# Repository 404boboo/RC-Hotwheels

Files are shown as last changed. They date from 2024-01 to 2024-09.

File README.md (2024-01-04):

# RC-Hotwheels
This project is a remote controlled Hotwheels. Here you can find the Ki-cad design files and STM32 project

This repository contains all the files and documentation for our DIY remote-controlled Hot Wheels car. We designed our own custom PCB using KiCad, featuring a NRF24L01 transceiver(We only used it as a receiver for now) for wireless communication, an H-bridge BD6211F-E2 to control a DC motor for propulsion, a 600mAh LiPo battery for power, and a linear servo motor for precise steering control.
## Folder Structure

- `Kicad Files`: Contains the schematic and gerber files for the PCB design.
  - `Libs`: Libraries for the components used in the KiCad.
- `Stm32F070F6P6TR`: STM32Cube project folder.
## Bill of Materials (BOM)

Check out our [Bill of Materials Spreadsheet](https://1drv.ms/x/s!AkUVCTQvexeIhbBXzQdKwvWQZ13EOg?e=rf4EnU) for a detailed list of components used in this project.
## Installation and Setup

### PCB (KiCad Files)

1. Download the KiCad software from [kicad.org](https://www.kicad.org/).
2. Open the KiCad project files in the `Kicad Files` folder.
3. Generate the gerber files for manufacturing.

### STM32Cube Project

-- TODO

### Hardware

1. Assemble the custom PCB according to the provided schematic.
2. Connect the NRF24L01 transceiver
-- To be updated..

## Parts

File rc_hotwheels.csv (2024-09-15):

Source: | D:\Studia\5th_semester\bondyra_project\project\RC-Hotwheels\KiCad-Files\rc_hotwheels.kicad_sch
Date: | 1/14/2024 6:13:28 PM
Tool: | Eeschema 7.0.5
Generator: | D:\Studia\kicad\7.0\bin\scripting\plugins/bom_csv_grouped_by_value_with_fp.py
Component Count: | 14
Ref | Qnty | Value | Cmp name | Footprint | Description | Vendor | DNP
BT1 | 1 | Battery_Cell | Battery_Cell | Library:Battery_Pads | Single-cell battery
C1, C2, C4 | 3 | 1uF | 885012209003 | C1uF:CAPC2012X135N | Multilayer Ceramic Chip Capacitor WCAP-CSGP Series 1210 1000000pF X7R1210105K010DFCT10000
C3 | 1 | 4.7uF | 885012209004 | C1uF:CAPC2012X135N | Multilayer Ceramic Chip Capacitor WCAP-CSGP Series 1210 4700000pF X7R1210475K010DFCT10000
C5 | 1 | 100nF | 885012209041 | C1uF:CAPC2012X135N | Multilayer Ceramic Chip Capacitor WCAP-CSGP Series 1210 100000pF X7R1210104K050DFCT10000
C6 | 1 | 10nF | 885012209035 | C1uF:CAPC2012X135N | Multilayer Ceramic Chip Capacitor WCAP-CSGP Series 1210 10000pF X7R1210103K050DFCT10000
IC1 | 1 | BD6211F-E2 | BD6211F-E2 | BD6211F-E2:SOIC127P620X171-8N | ROHM BD6211F-E2, Full Bridge Motor Driver Half-Bridge,, 8-Pin SOP
IC2 | 1 | MIC5504-3.3YM5-TR | MIC5504-3.3YM5-TR | MIC5504-3.3YM5-TR:SOT95P280X145-5N | MICROCHIP - MIC5504-3.3YM5-TR - LDO VOLT REG, 0.3A, 3.3V, SOT-23-5
S1 | 1 | OS102011MS2QN1 | OS102011MS2QN1 | OS102011MA1QN1 | Switch Slide Miniature SPDT 0.1A 12VDC Through Hole Slide Switch SPDT On-On 0.1 A@ 12 V dc Slide
S3 | 1 | Li-Ion 18650 battery charging | OS102011MS2QN1_1 | Library:Battery_Pads | Switch Slide Miniature SPDT 0.1A 12VDC Through Hole Slide Switch SPDT On-On 0.1 A@ 12 V dc Slide
SM1 | 1 | Motor_Servo | Motor_Servo | Library:Servo_Motor | Servo Motor (Futaba, HiTec, JR connector)
U1 | 1 | STM32F070F6P6 | STM32F070F6P6 | STM32F070F6P6:SOP65P640X120-20N
U3 | 1 | NRF24L01_Breakout | NRF24L01_Breakout_1 | RF_Module:nRF24L01_Breakout | Ultra low power 2.4GHz RF Transceiver, Carrier PCB

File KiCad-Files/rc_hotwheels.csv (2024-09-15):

Source: | D:\Studia\5th_semester\bondyra_project\project\RC-Hotwheels\KiCad-Files\rc_hotwheels.kicad_sch
Date: | 1/14/2024 18:13
Tool: | Eeschema 7.0.5
Generator: | D:\Studia\kicad\7.0\bin\scripting\plugins/bom_csv_grouped_by_value_with_fp.py
Component Count: | 14
Ref | Qnty | Value | Cmp name | Footprint | Description | Vendor | Price 1 piece | Price 1 PCB | Price for 1 (10 pieces) | Price 10 PCB | Price for 1 (100 piece) | Price 100 PCB
BT1 | 1 | 600mAh | Battery_Cell | Library:Battery_Pads | Single-cell battery | unknown/allegro | PLN 32.99 | PLN 32.99 | PLN 32.99 | PLN 329.90 | PLN 32.99 | PLN 3,299.00
C1, C2, C4 | 3 | 1uF | 8.85012E+11 | C1uF:CAPC2012X135N | Multilayer Ceramic Chip Capacitor WCAP-CSGP Series 1210 1000000pF X7R1210105K010DFCT10000 | https://pl.farnell.com/en-PL | PLN 1.02 | PLN 1.02 | PLN 1.02 | PLN 10.20 | PLN 0.29 | PLN 87.00
C3 | 1 | 4.7uF | 8.85012E+11 | C1uF:CAPC2012X135N | Multilayer Ceramic Chip Capacitor WCAP-CSGP Series 1210 4700000pF X7R1210475K010DFCT10000 | https://pl.farnell.com/en-PL | PLN 0.48 | PLN 0.48 | PLN 0.48 | PLN 4.80 | PLN 0.27 | PLN 27.00
C5 | 1 | 100nF | 8.85012E+11 | C1uF:CAPC2012X135N | Multilayer Ceramic Chip Capacitor WCAP-CSGP Series 1210 100000pF X7R1210104K050DFCT10000 | https://pl.farnell.com/en-PL | PLN 0.21 | PLN 0.21 | PLN 0.21 | PLN 2.10 | PLN 0.18 | PLN 18.00
C6 | 1 | 10nF | 8.85012E+11 | C1uF:CAPC2012X135N | Multilayer Ceramic Chip Capacitor WCAP-CSGP Series 1210 10000pF X7R1210103K050DFCT10000 | https://pl.farnell.com/en-PL | PLN 0.15 | PLN 0.15 | PLN 0.15 | PLN 1.50 | PLN 0.13 | PLN 13.00
IC1 | 1 | BD6211F-E2 | BD6211F-E2 | BD6211F-E2:SOIC127P620X171-8N | ROHM BD6211F-E2, Full Bridge Motor Driver Half-Bridge,, 8-Pin SOP | https://pl.farnell.com/en-PL | PLN 10.55 | PLN 10.55 | PLN 7.69 | PLN 76.90 | PLN 7.20 | PLN 720.00
IC2 | 1 | MIC5504-3.3YM5-TR | MIC5504-3.3YM5-TR | MIC5504-3.3YM5-TR:SOT95P280X145-5N | MICROCHIP - MIC5504-3.3YM5-TR - LDO VOLT REG, 0.3A, 3.3V, SOT-23-5 | https://pl.farnell.com/en-PL | PLN 0.64 | PLN 0.64 | PLN 0.64 | PLN 6.40 | PLN 0.56 | PLN 56.00
S1 | 1 | OS102011MS2QN1 | OS102011MS2QN1 | OS102011MA1QN1 | Switch Slide Miniature SPDT 0.1A 12VDC Through Hole Slide Switch SPDT On-On 0.1 A@ 12 V dc Slide | https://pl.farnell.com/en-PL | PLN 2.79 | PLN 2.79 | PLN 2.79 | PLN 27.90 | PLN 2.02 | PLN 202.00
S3 | 1 | Li-Ion battery charging | TP4056 | Library:Battery_Pads | Switch Slide Miniature SPDT 0.1A 12VDC Through Hole Slide Switch SPDT On-On 0.1 A@ 12 V dc Slide | unknown/allegro | PLN 2.99 | PLN 2.99 | PLN 2.99 | PLN 29.90 | PLN 2.99 | PLN 299.00
SM1 | 1 | Motor_Servo | Motor_Servo | Library:Servo_Motor | Servo Motor (Futaba, HiTec, JR connector) | unknown/allegro | PLN 9.88 | PLN 9.88 | PLN 9.88 | PLN 98.80 | PLN 9.88 | PLN 988.00
U1 | 1 | STM32F070F6P6 | STM32F070F6P6 | STM32F070F6P6:SOP65P640X120-20N | Microprocessor | https://pl.farnell.com/en-PL | PLN 8.18 | PLN 8.18 | PLN 6.57 | PLN 65.70 | PLN 5.81 | PLN 581.00
U3 | 1 | NRF24L01_Breakout | NRF24L01_Breakout_1 | RF_Module:nRF24L01_Breakout | Ultra low power 2.4GHz RF Transceiver, Carrier PCB | https://sklep.msalamon.pl/ | PLN 5.99 | PLN 5.99 | PLN 5.99 | PLN 59.90 | PLN 5.99 | PLN 599.00
 | 1 |  | Silnik szczotkowy DC 1,5V-3,5V klasy 130 |  | DC motor 1,5V-3,5V | unknown/allegro | PLN 6.80 | PLN 6.80 | PLN 6.80 | PLN 68.00 | PLN 6.80 | PLN 680.00
 |  |  |  |  |  |  | Total 1 | Total 1 PCB | Total 10 | Total 10 PCB | Total 100 | Total 100 PCB
 |  |  |  |  |  |  | PLN 82.67 | PLN 82.67 | PLN 78.20 | PLN 782.00 | PLN 75.11 | PLN 7,569.00

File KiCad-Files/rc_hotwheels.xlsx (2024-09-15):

Source: | D:\Studia\5th_semester\bondyra_project\project\RC-Hotwheels\KiCad-Files\rc_hotwheels.kicad_sch
Date: | 2024-01-14 18:13
Tool: | Eeschema 7.0.5
Generator: | D:\Studia\kicad\7.0\bin\scripting\plugins/bom_csv_grouped_by_value_with_fp.py
Component Count: | 14
Ref | Qnty | Value | Cmp name | Footprint | Description | Vendor | Price 1 piece | Price 1 PCB | Price for 1 (10 pieces) | Price 10 PCB | Price for 1 (100 piece) | Price 100 PCB
BT1 | 1 | 600mAh | Battery_Cell | Library:Battery_Pads | Single-cell battery | unknown/allegro (https://allegro.pl/oferta/akumulator-bateria-gps-navi-600mah-3-7v-3-przewody-11314725293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) | PLN 32.99 | PLN 32.99 | PLN 32.99 | PLN 329.90 | PLN 32.99 | PLN 3,299.00
C1, C2, C4 | 3 | 1uF | 885012000000 | C1uF:CAPC2012X135N | Multilayer Ceramic Chip Capacitor WCAP-CSGP Series 1210 1000000pF X7R1210105K010DFCT10000 | farnell (https://pl.farnell.com/wurth-elektronik/885012207022/cap-1-f-10v-10-x7r-0805/dp/2534053) | PLN 1.02 | PLN 1.02 | PLN 1.02 | PLN 10.20 | PLN 0.29 | PLN 87.00
C3 | 1 | 4.7uF | 885012000000 | C1uF:CAPC2012X135N | Multilayer Ceramic Chip Capacitor WCAP-CSGP Series 1210 4700000pF X7R1210475K010DFCT10000 | farnell (https://pl.farnell.com/tdk/c2012x7r1a475k125ac/cap-4-7-f-10v-10-x7r-0805/dp/2346936) | PLN 0.48 | PLN 0.48 | PLN 0.48 | PLN 4.80 | PLN 0.27 | PLN 27.00
C5 | 1 | 100nF | 885012000000 | C1uF:CAPC2012X135N | Multilayer Ceramic Chip Capacitor WCAP-CSGP Series 1210 100000pF X7R1210104K050DFCT10000 | farnell (https://pl.farnell.com/wurth-elektronik/885012207016/cap-0-1-f-10v-10-x7r-0805/dp/2534051) | PLN 0.21 | PLN 0.21 | PLN 0.21 | PLN 2.10 | PLN 0.18 | PLN 18.00
C6 | 1 | 10nF | 885012000000 | C1uF:CAPC2012X135N | Multilayer Ceramic Chip Capacitor WCAP-CSGP Series 1210 10000pF X7R1210103K050DFCT10000 | farnell (https://pl.farnell.com/wurth-elektronik/885012207011/cap-0-01-f-10v-10-x7r-0805/dp/2534050) | PLN 0.15 | PLN 0.15 | PLN 0.15 | PLN 1.50 | PLN 0.13 | PLN 13.00
IC1 | 1 | BD6211F-E2 | BD6211F-E2 | BD6211F-E2:SOIC127P620X171-8N | ROHM BD6211F-E2, Full Bridge Motor Driver Half-Bridge,, 8-Pin SOP | farnell (https://pl.farnell.com/en-PL/rohm/bd6211f-e2/ic-h-bridge-driver-7v-1a-sop8/dp/1716259) | PLN 10.55 | PLN 10.55 | PLN 7.69 | PLN 76.90 | PLN 7.20 | PLN 720.00
IC2 | 1 | MIC5504-3.3YM5-TR | MIC5504-3.3YM5-TR | MIC5504-3.3YM5-TR:SOT95P280X145-5N | MICROCHIP - MIC5504-3.3YM5-TR - LDO VOLT REG, 0.3A, 3.3V, SOT-23-5 | farnell (https://pl.farnell.com/en-PL/microchip/mic5504-3-3ym5-tr/ldo-volt-reg-0-3a-3-3v-sot-23/dp/2510377?st=mic5504) | PLN 0.64 | PLN 0.64 | PLN 0.64 | PLN 6.40 | PLN 0.56 | PLN 56.00
S1 | 1 | OS102011MS2QN1 | OS102011MS2QN1 | OS102011MA1QN1 | Switch Slide Miniature SPDT 0.1A 12VDC Through Hole Slide Switch SPDT On-On 0.1 A@ 12 V dc Slide | farnell (https://pl.farnell.com/c-k-components/os102011ma1qn1/switch-spdt-0-1a-12v-pcb-r-a/dp/1201431?st=os102011ma1qn1) | PLN 2.79 | PLN 2.79 | PLN 2.79 | PLN 27.90 | PLN 2.02 | PLN 202.00
S3 | 1 | Li-Ion battery charging | TP4056 | Library:Battery_Pads | Switch Slide Miniature SPDT 0.1A 12VDC Through Hole Slide Switch SPDT On-On 0.1 A@ 12 V dc Slide | unknown/allegro (https://allegro.pl/oferta/ladowarka-akumulatora-li-ion-tp4056-5v-micro-usb-10795965827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) | PLN 2.99 | PLN 2.99 | PLN 2.99 | PLN 29.90 | PLN 2.99 | PLN 299.00
SM1 | 1 | Motor_Servo | Motor_Servo | Library:Servo_Motor | Servo Motor (Futaba, HiTec, JR connector) | unknown/allegro (https://allegro.pl/oferta/linear-serwo-1-5g-serwo-15001884361) | PLN 9.88 | PLN 9.88 | PLN 9.88 | PLN 98.80 | PLN 9.88 | PLN 988.00
U1 | 1 | STM32F070F6P6 | STM32F070F6P6 | STM32F070F6P6:SOP65P640X120-20N | Microprocessor | farnell (https://pl.farnell.com/en-PL/stmicroelectronics/stm32f070f6p6tr/mcu-32bit-48mhz-tssop-20/dp/3129808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) | PLN 8.18 | PLN 8.18 | PLN 6.57 | PLN 65.70 | PLN 5.81 | PLN 581.00
U3 | 1 | NRF24L01_Breakout | NRF24L01_Breakout_1 | RF_Module:nRF24L01_Breakout | Ultra low power 2.4GHz RF Transceiver, Carrier PCB | msalamon (https://sklep.msalamon.pl/produkt/modul-radiowy-nrf24l01-24-ghz-mini-smd/) | PLN 5.99 | PLN 5.99 | PLN 5.99 | PLN 59.90 | PLN 5.99 | PLN 599.00
 | 1 |  | Silnik szczotkowy DC 1,5V-3,5V klasy 130 |  | DC motor 1,5V-3,5V | unknown/allegro (https://allegro.pl/oferta/silnik-szczotkowy-dc-1-5v-3-5v-klasy-130-8897411135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) | PLN 6.80 | PLN 6.80 | PLN 6.80 | PLN 68.00 | PLN 6.80 | PLN 680.00
 |  |  |  |  |  |  | Total 1 | Total 1 PCB | Total 10 | Total 10 PCB | Total 100 | Total 100 PCB
 |  |  |  |  |  |  | PLN 82.67 | PLN 82.67 | PLN 78.20 | PLN 782.00 | PLN 75.11 | PLN 7,569.00

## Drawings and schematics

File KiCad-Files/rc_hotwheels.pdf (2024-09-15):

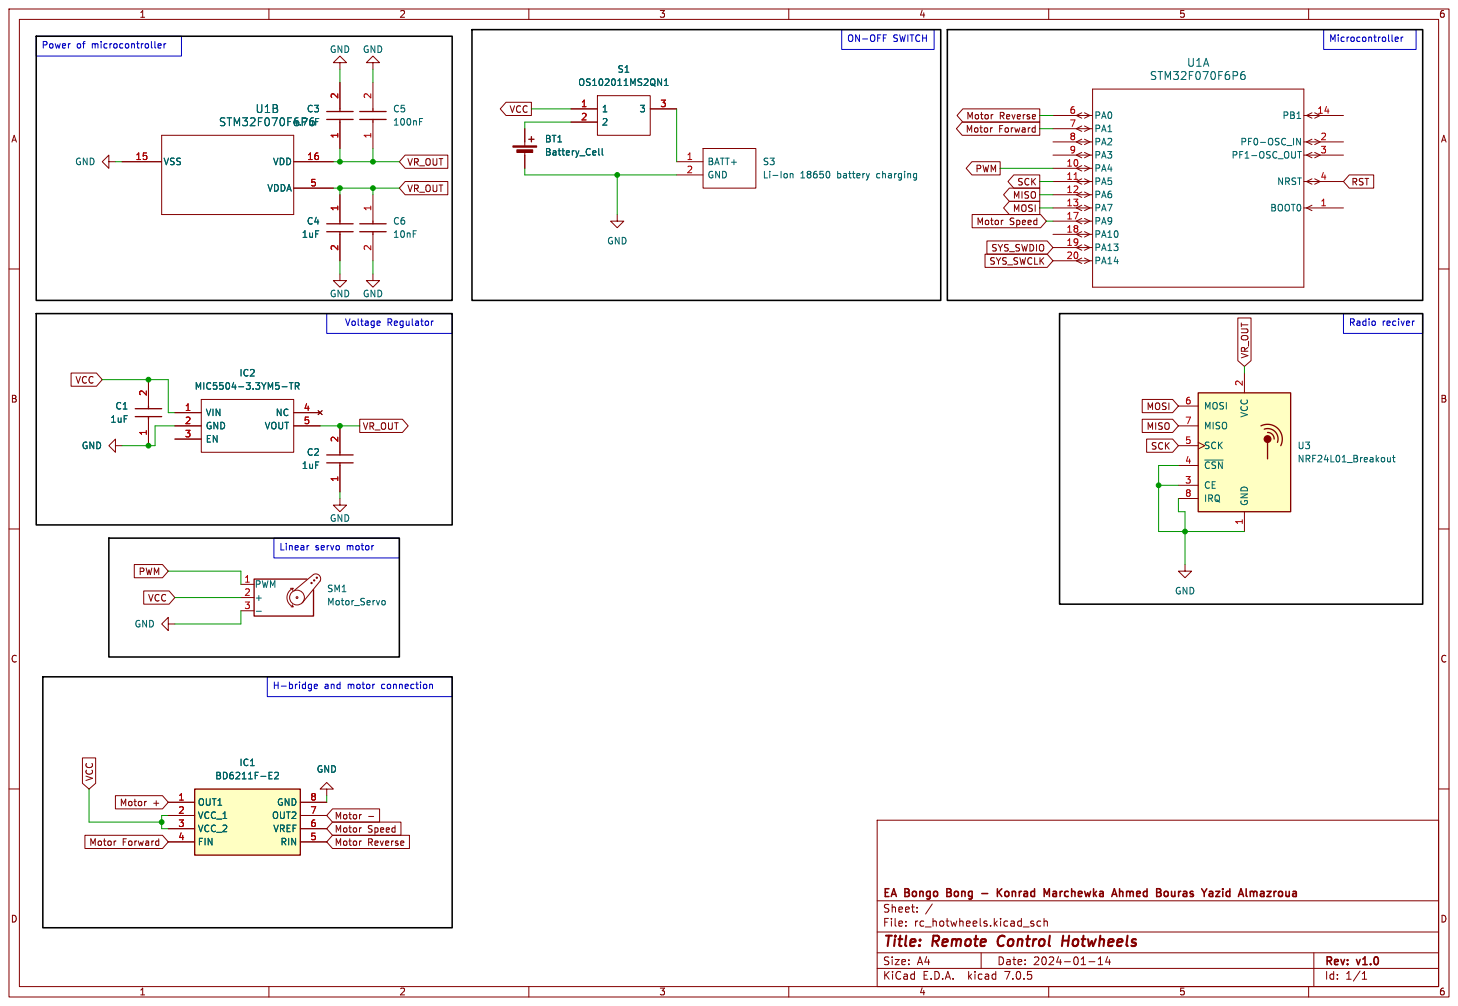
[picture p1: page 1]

VCC Motor -
SYS_SWDIO Motor Forward VR_OUT VR_OUT Motor Reverse

2 CE 3 ~{CSN} 4 SCK 5 MOSI 6 MISO 7

Id: 1/1 Title: Remote Control Hotwheels

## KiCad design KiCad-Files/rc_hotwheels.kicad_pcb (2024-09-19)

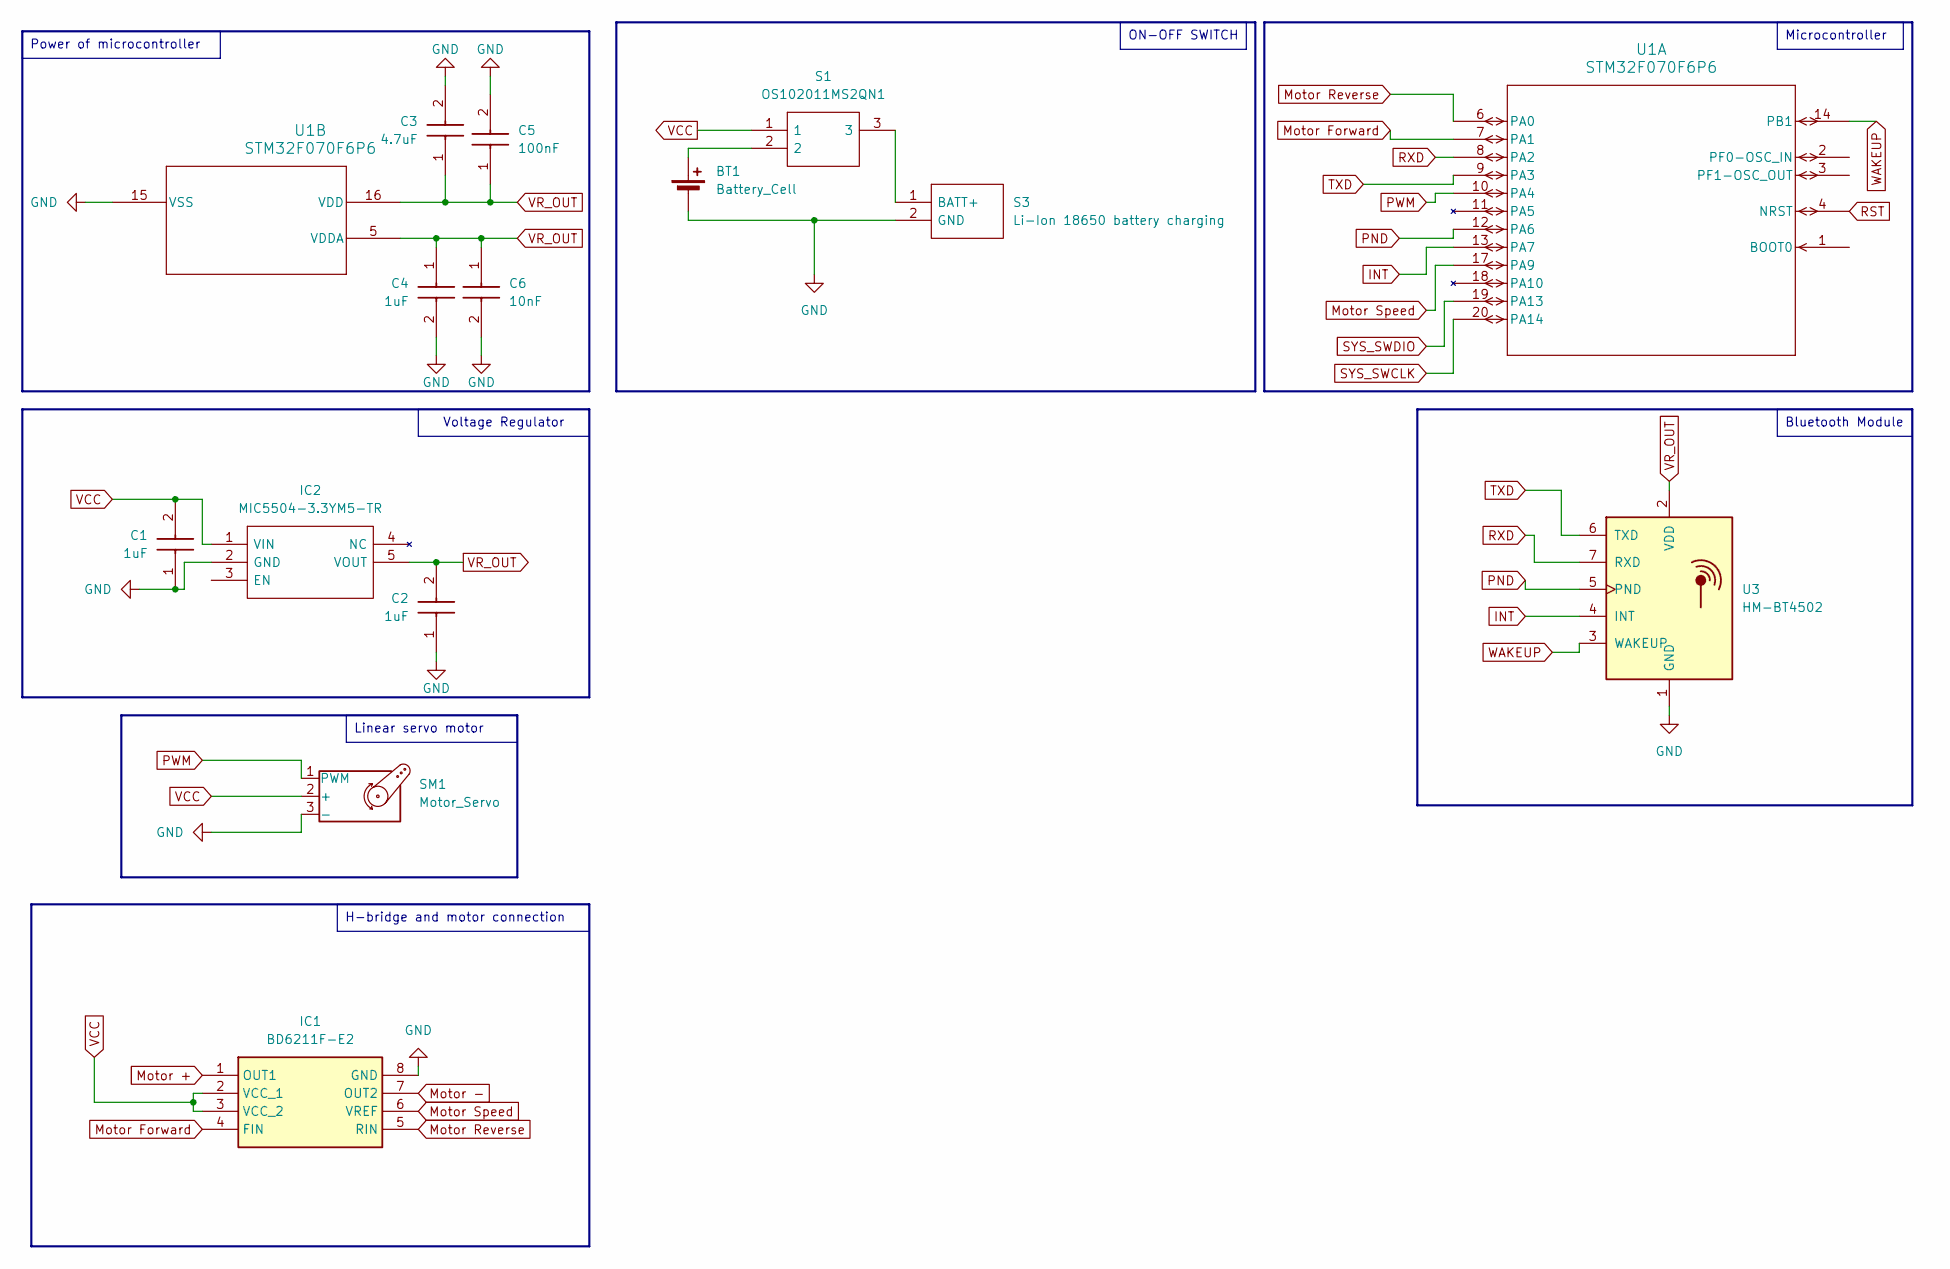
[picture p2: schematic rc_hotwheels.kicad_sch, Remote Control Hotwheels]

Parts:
BT1: Battery_Cell; Battery_Pads
C1, C2, C4: 1uF; CAPC2012X135N; Manufacturer_Part_Number 885012209003
C3: 4.7uF; CAPC2012X135N; Manufacturer_Part_Number 885012209004
C5: 100nF; CAPC2012X135N; Manufacturer_Part_Number 885012209041
C6: 10nF; CAPC2012X135N; Manufacturer_Part_Number 885012209035
IC1: BD6211F-E2; SOIC127P620X171-8N; Manufacturer_Part_Number BD6211F-E2
IC2: MIC5504-3.3YM5-TR; SOT95P280X145-5N; Manufacturer_Part_Number MIC5504-3.3YM5-TR; Mouser Part Number 998-MIC5504-3.3YM5TR
S1: OS102011MS2QN1; OS102011MA1QN1; Manufacturer_Part_Number OS102011MS2QN1
S3: Li-Ion 18650 battery charging; Battery_Pads; Manufacturer_Part_Number OS102011MS2QN1
SM1: Motor_Servo; Servo_Motor
U1: STM32F070F6P6; SOP65P640X120-20N
U3: HM-BT4502; nRF24L01_Breakout

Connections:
GND: BT1.2 (-), C1.1, C2.1, C3.2, C4.2, C5.2, C6.2, IC1.8 (GND), IC2.2 (GND), S3.2 (GND), SM1.3 (-), U1.15 (VSS), U3.1 (GND), U3.8; also elsewhere on the board
INT: U1.13 (PA7), U3.4 (INT)
Motor +: IC1.1 (OUT1); also elsewhere on the board
Motor -: IC1.7 (OUT2); also elsewhere on the board
Motor Forward: IC1.4 (FIN), U1.7 (PA1)
Motor Reverse: IC1.5 (RIN), U1.6 (PA0)
Motor Speed: IC1.6 (VREF), U1.17 (PA9)
unnamed: BT1.1 (+), S1.2
unnamed: S1.3, S3.1 (BATT+)
PND: U1.12 (PA6), U3.5 (PND)
PWM: SM1.1 (PWM), U1.10 (PA4)
RST: U1.4 (NRST); also elsewhere on the board
RXD: U1.8 (PA2), U3.7 (RXD)
SYS_SWCLK: U1.20 (PA14); also elsewhere on the board
SYS_SWDIO: U1.19 (PA13); also elsewhere on the board
TXD: U1.9 (PA3), U3.6 (TXD)
VCC: C1.2, IC1.2 (VCC_1), IC1.3 (VCC_2), IC2.1 (VIN), S1.1, SM1.2 (+)
VR_OUT: C2.2, C3.1, C4.1, C5.1, C6.1, IC2.5 (VOUT), U1.5 (VDDA), U1.16 (VDD), U3.2 (VDD); also elsewhere on the board
WAKEUP: U1.14 (PB1), U3.3 (WAKEUP)

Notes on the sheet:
Bluetooth Module
ON-OFF SWITCH
Linear servo motor
Voltage Regulator
Power of microcontroller
H-bridge and motor connection
Microcontroller

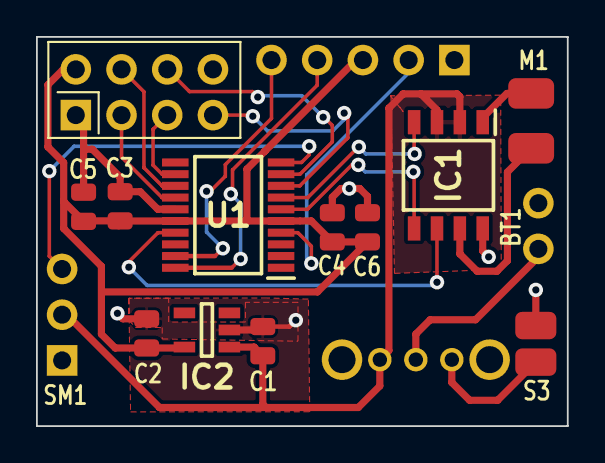
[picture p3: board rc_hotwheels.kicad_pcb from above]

Board: 2 copper layers, 29.5 x 21.6 mm, 16 parts (1 on the bottom side), 19 nets.

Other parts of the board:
M1: Motor_Connection
ST: ST_Link

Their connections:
GND: ST.1; also elsewhere on the board
Motor +: M1.2; also elsewhere on the board
Motor -: M1.1; also elsewhere on the board
RST: ST.2; also elsewhere on the board
SYS_SWCLK: ST.4; also elsewhere on the board
SYS_SWDIO: ST.5; also elsewhere on the board
VR_OUT: ST.3; also elsewhere on the board

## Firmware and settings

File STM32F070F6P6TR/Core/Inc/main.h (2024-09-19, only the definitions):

#define MotorReverse_Pin GPIO_PIN_0
#define MotorReverse_GPIO_Port GPIOA
#define MotorForward_Pin GPIO_PIN_1
#define MotorForward_GPIO_Port GPIOA
#define Servo_Control_Pin GPIO_PIN_4
#define Servo_Control_GPIO_Port GPIOA
#define PDN_Pin GPIO_PIN_6
#define PDN_GPIO_Port GPIOA
#define INT_Pin GPIO_PIN_7
#define INT_GPIO_Port GPIOA
#define WAKEUP_Pin GPIO_PIN_1
#define WAKEUP_GPIO_Port GPIOB
#define Motor_Speed_Pin GPIO_PIN_9
#define Motor_Speed_GPIO_Port GPIOA

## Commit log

2023-11-23 Starting point
    [rc_hotwheels.kicad_pcb, rc_hotwheels.kicad_sch]
2023-11-28 Improved github project files structure.
    [rc_hotwheels.kicad_pcb, rc_hotwheels.kicad_sch]
2023-11-28 Added H-Bridge symbol and connection.
    [rc_hotwheels.kicad_sch]
2023-11-29 Added receiver symbol and connections
    [rc_hotwheels.kicad_sch]
2023-11-29 Creation of STM32 project
2023-11-29 Updated the nRF24L01 connection to the MCU.
    [rc_hotwheels.kicad_sch]
2023-11-29 Servo motor
    [rc_hotwheels.kicad_sch]
2023-11-29 Added name tags to components
    [rc_hotwheels.kicad_sch]
2023-11-29 visual update
    [rc_hotwheels.kicad_sch]
2023-11-29 Added the PMW pin for servo on STM32
2023-11-29 changed the servo pin to p4
2023-11-30 Enabled Debug Serial Wire for the MCU
2023-12-04 Motor connections and configurations updated(Forward, Reverse, Speed)
    [rc_hotwheels.kicad_sch]
2023-12-04 Servo motor connection and configurations updated.
    [rc_hotwheels.kicad_sch]
2023-12-11 Added Voltage Regulator symbol, connections and improved STM pinout user label
    [rc_hotwheels.kicad_sch]
2023-12-13 Added capacitors to the MCU and Voltage Regulator
    [rc_hotwheels.kicad_sch]
2023-12-22 Capacitors footprints added
    Capacitor_THT:C_Rect_L4.6mm_W2.0mm_P2.50mm_MKS02_FKP02
    [rc_hotwheels.kicad_pcb, rc_hotwheels.kicad_sch]
2023-12-22 Servo motor connection
    Deleted unused component - servo motor, instead used mounting holes
    [rc_hotwheels.kicad_sch]
2023-12-22 Mounting holes footprints added
    [rc_hotwheels.kicad_sch]
2023-12-23 Added more capacitors for power supply of MCU
    [rc_hotwheels.kicad_sch]
2023-12-23 Added all library files for KiCad
2023-12-23 Footprint and Symbol libraries imported
2023-12-25 Updated MCU footprint
    [rc_hotwheels.kicad_sch]
2023-12-28 Created PCB Design
    - Placed Components at the right place. Connected Voltage Regulator chip to MCU.
    - Changed Capacitors Footprint and Symbol.
    [rc_hotwheels.kicad_pcb, rc_hotwheels.kicad_sch]
2023-12-28 PCB Design
    Connecting the Transceiver
    [rc_hotwheels.kicad_pcb]
2023-12-29 PCB updated
    Mostly connections for H-Bride to motor and Servo Motor.
2023-12-30 Fixed all schematic errors.
    [rc_hotwheels.kicad_pcb, rc_hotwheels.kicad_sch]
2023-12-30 Created and imported footprints for Battery and Servo Motor connection
2023-12-31 PCB V2.0
    [rc_hotwheels.kicad_pcb, rc_hotwheels.kicad_sch]
2024-01-01 PCB V2.1
    - Reduced the height size of the PCB(moved components closer to each other).
    - Connected all GNDs to each other.
2024-01-10 Updated all power traces
    [rc_hotwheels.kicad_pcb]
2024-01-10 Updated Capcitors libs
    [rc_hotwheels.kicad_pcb, rc_hotwheels.kicad_sch]
2024-01-11 PCB V2.2
    -Updated Capacitors footprint
    -Added reset pin for the MCU.
    -PCB design improved
    [rc_hotwheels.kicad_pcb, rc_hotwheels.kicad_sch]
2024-01-14 Fixed GNDS not connected.
    [rc_hotwheels.kicad_pcb]
2024-01-14 PCB Update
    Fixed all errors & warnings
    Made the thermal reliefs bigger
2024-01-14 Merge branch 'master' of https://github.com/404boboo/RC-Hotwheels
    Small changes in tracing
    [rc_hotwheels.kicad_pcb]
2024-01-14 Files update
    Schematic PDF added
2024-01-14 Files update
    Gerber and drill files added
    [rc_hotwheels-B_Cu.gbr, rc_hotwheels-B_Mask.gbr, rc_hotwheels-B_Paste.gbr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]
2024-01-14 Files update
    Bill of materials added
    [rc_hotwheels.csv, rc_hotwheels.kicad_pcb, rc_hotwheels.kicad_sch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]
2024-09-19 Changed Radio Receiver to Bluetooth Module
    [rc_hotwheels.kicad_pcb, rc_hotwheels.kicad_sch]

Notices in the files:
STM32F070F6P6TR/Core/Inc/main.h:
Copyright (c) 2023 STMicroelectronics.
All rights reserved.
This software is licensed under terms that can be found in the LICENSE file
